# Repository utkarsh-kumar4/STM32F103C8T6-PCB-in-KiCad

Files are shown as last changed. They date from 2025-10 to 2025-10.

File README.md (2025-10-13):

<h1 align="center">⚙️ STM32F103C8T6 Custom PCB in Kicad</h1>

<h2>📘 Overview</h2>
<p>
This project presents a fully designed and routed PCB based on the <b>STM32F103C8T6</b> microcontroller — a popular ARM Cortex-M3 based MCU used widely in embedded systems, control units, and IoT applications. 
The design covers schematic creation, PCB layout, 3D rendering, and Gerber file generation using <b>KiCad 9.0.4</b>. 
The board integrates essential power regulation, programming/debugging headers, and communication interfaces, making it suitable for both learning and prototyping environments.
</p>

<hr>

<h2>🧩 Features</h2>
<ul>
  <li>Microcontroller: <b>STM32F103C8T6</b> (ARM Cortex-M3, 72 MHz, 64 KB Flash)</li>
  <li>Interfaces: UART, I2C, USB, and SWD Debug</li>
  <li>16 MHz Crystal Oscillator for stable system clock</li>
  <li>AMS1117-3.3V linear regulator from USB VBUS (5V to 3.3V)</li>
  <li>On-board BOOT0 switch for flash and system memory booting</li>
  <li>Compact double-layer PCB with decoupling and bulk capacitors</li>
  <li>All standard headers exposed for breadboard-friendly prototyping</li>
</ul>

<hr>

<h2>🔧 Circuit Design Details</h2>

<h3>Microcontroller Section</h3>
<p>
The core of the design revolves around the <b>STM32F103C8T6</b>. Proper pin mapping and peripheral allocation were done using <b>STM32CubeIDE</b> before schematic creation in KiCad. 
The nomenclature follows standard STM32 conventions:
<ul>
  <li><b>VDD / VDDA</b>: 3.3V supply</li>
  <li><b>VSS / VSSA</b>: Ground reference</li>
  <li><b>VBAT</b>: Backup domain supply (optional in this design)</li>
</ul>
</p>

<h3>Power Supply</h3>
<p>
Power is supplied via the USB connector. The <b>AMS1117-3.3V regulator</b> converts 5V (VBUS) to 3.3V for the MCU and peripherals. 
A combination of <b>decoupling capacitors (100nF per VDD pin)</b> and a <b>bulk capacitor (22µF)</b> ensures voltage stability. 
A <b>ferrite bead (FB1)</b> is used for VDDA filtering to isolate analog noise.
</p>

<h3>Clock Circuit</h3>
<p>
A <b>16 MHz crystal oscillator</b> (Y1) provides the external clock source. Load capacitors (C12, C13) are calculated based on crystal datasheet using:
<code>CL = 2 × (C_L - C_stray)</code>. 
The crystal’s ground pads are tied to <b>Crystal_GND24</b> for EMI reduction.
</p>

<h3>Reset and Boot Configuration</h3>
<p>
The <b>NRST</b> pin is connected to a pull-up resistor and reset header, allowing manual or external resets. 
A <b>BOOT0 switch</b> lets users toggle between Flash memory boot and system memory boot modes for easy firmware flashing.
</p>

<h3>USB Interface</h3>
<p>
The <b>Micro USB Type-B connector</b> provides both power and data interface. 
Differential data lines (<b>USB_D+</b> and <b>USB_D−</b>) are routed as a <b>differential pair</b> in KiCad for signal integrity. 
The <b>VBUS</b> pin powers the regulator, and <b>USB shield</b> is tied to board ground through high-value resistance to reduce noise coupling.
</p>

<h3>Communication Interfaces</h3>
<p>
The board exposes the following interfaces:
<ul>
  <li><b>UART</b> – USART1_TX, USART1_RX for serial communication</li>
  <li><b>I2C</b> – I2C1_SCL, I2C1_SDA for sensor and peripheral interfacing</li>
  <li><b>SWD</b> – Serial Wire Debug (PA13, PA14) for programming and debugging</li>
</ul>
These headers simplify firmware upload and real-time debugging using ST-Link or similar tools.
</p>

<hr>

<h2>💻 KiCad Project Workflow</h2>
<p>
The PCB was designed in <b>KiCad</b> following standard embedded design practices. ERC (Electrical Rules Check) and DRC (Design Rules Check) were performed to ensure design integrity before Gerber generation.
</p>

<ul>
  <li><b>ERC:</b> Validates schematic-level connections and symbol consistency.</li>
  <li><b>DRC:</b> Checks trace clearances, copper spacing, and via placements.</li>
  <li><b>Gerber Files:</b> Generated for manufacturing and fabrication verification.</li>
</ul>

<hr>

<h2>🧠 Learnings</h2>
<p>
This project helped reinforce key embedded hardware design concepts:
<ul>
  <li>Understanding STM32 power domains (VDD, VDDA, VBAT)</li>
  <li>Implementing decoupling and bulk capacitors for stable operation</li>
  <li>Applying ferrite beads for analog noise isolation</li>
  <li>Routing differential USB pairs in KiCad</li>
  <li>Debugging using SWD and BOOT0 configuration</li>
  <li>Generating and verifying ERC/DRC-compliant Gerber files</li>
</ul>
It also provided insight into the workflow of transforming a schematic into a professional-grade PCB suitable for embedded applications.
</p>

<hr>

<h2>📷 Project Images</h2>
<h3>🔹 Schematic Design</h3>
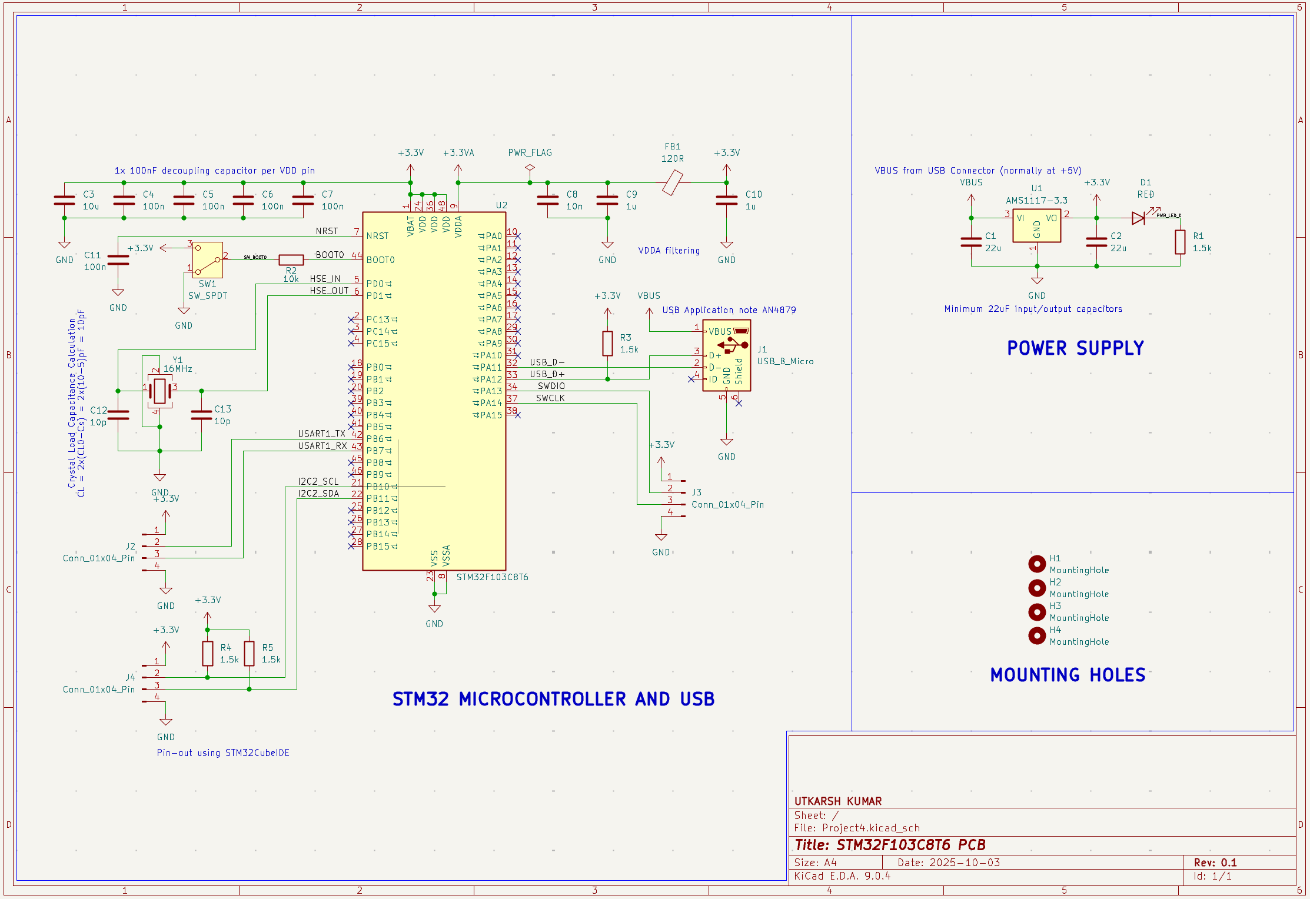
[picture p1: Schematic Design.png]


<h3>🔹 PCB Layout</h3>
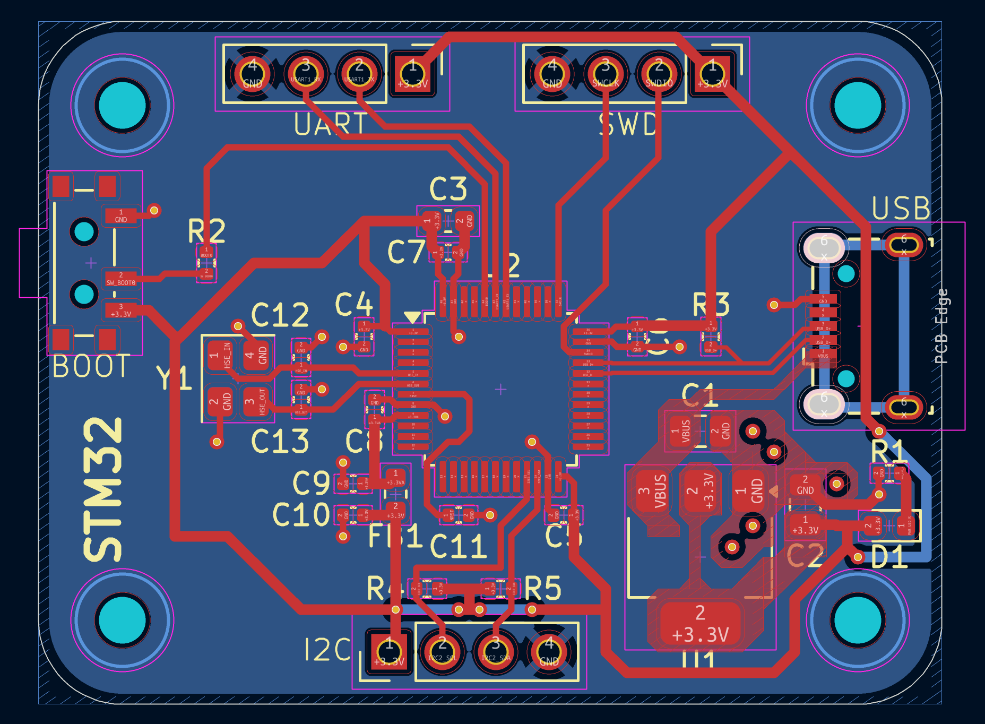
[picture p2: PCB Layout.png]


<h3>🔹 3D Board View</h3>
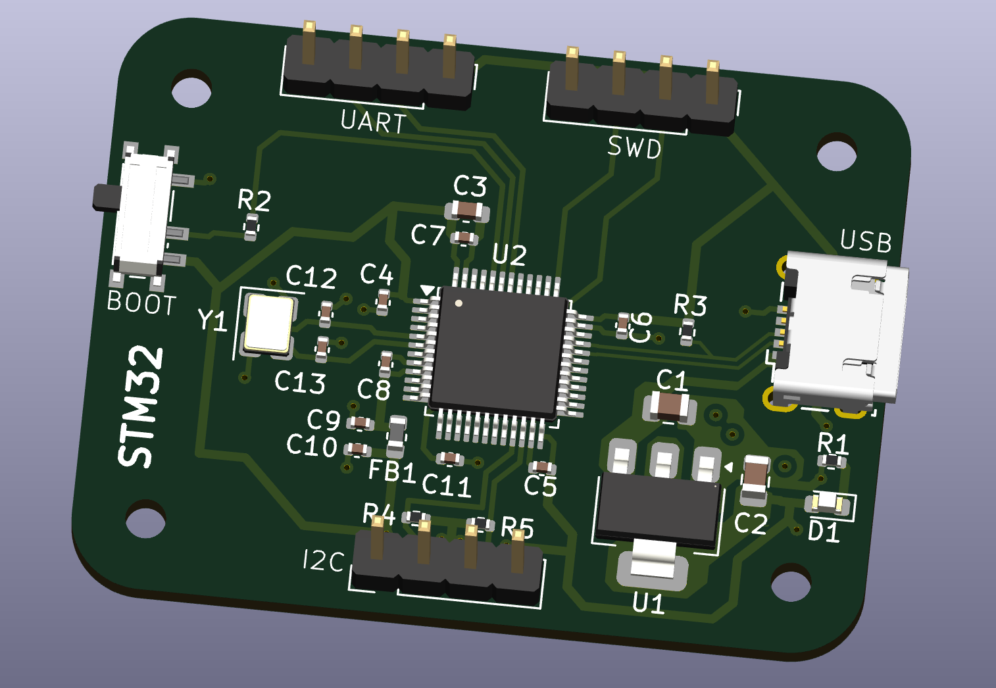
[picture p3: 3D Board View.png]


## Author 👤
[Utkarsh Kumar](https://github.com/utkarsh-kumar4) 👨🏻‍💻🎓

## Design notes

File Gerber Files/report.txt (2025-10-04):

Plotted to '/Users/homefolder/Desktop/KiCad Project/Project4/Project4-F_Cu.gbr'.
Plotted to '/Users/homefolder/Desktop/KiCad Project/Project4/Project4-B_Cu.gbr'.
Plotted to '/Users/homefolder/Desktop/KiCad Project/Project4/Project4-F_Paste.gbr'.
Plotted to '/Users/homefolder/Desktop/KiCad Project/Project4/Project4-B_Paste.gbr'.
Plotted to '/Users/homefolder/Desktop/KiCad Project/Project4/Project4-F_Silkscreen.gbr'.
Plotted to '/Users/homefolder/Desktop/KiCad Project/Project4/Project4-B_Silkscreen.gbr'.
Plotted to '/Users/homefolder/Desktop/KiCad Project/Project4/Project4-F_Mask.gbr'.
Plotted to '/Users/homefolder/Desktop/KiCad Project/Project4/Project4-B_Mask.gbr'.
Plotted to '/Users/homefolder/Desktop/KiCad Project/Project4/Project4-Edge_Cuts.gbr'.
Created Gerber job file '/Users/homefolder/Desktop/KiCad Project/Project4/Project4-job.gbrjob'.
Info: Done.
Plotted to '/Users/homefolder/Desktop/KiCad Project/Project4/Gerber Files/Project4-F_Cu.gbr'.
Plotted to '/Users/homefolder/Desktop/KiCad Project/Project4/Gerber Files/Project4-B_Cu.gbr'.
Plotted to '/Users/homefolder/Desktop/KiCad Project/Project4/Gerber Files/Project4-F_Paste.gbr'.
Plotted to '/Users/homefolder/Desktop/KiCad Project/Project4/Gerber Files/Project4-B_Paste.gbr'.
Plotted to '/Users/homefolder/Desktop/KiCad Project/Project4/Gerber Files/Project4-F_Silkscreen.gbr'.
Plotted to '/Users/homefolder/Desktop/KiCad Project/Project4/Gerber Files/Project4-B_Silkscreen.gbr'.
Plotted to '/Users/homefolder/Desktop/KiCad Project/Project4/Gerber Files/Project4-F_Mask.gbr'.
Plotted to '/Users/homefolder/Desktop/KiCad Project/Project4/Gerber Files/Project4-B_Mask.gbr'.
Plotted to '/Users/homefolder/Desktop/KiCad Project/Project4/Gerber Files/Project4-Edge_Cuts.gbr'.
Created Gerber job file '/Users/homefolder/Desktop/KiCad Project/Project4/Gerber Files/Project4-job.gbrjob'.
Info: Done.
Info: Done.
Info: Done.

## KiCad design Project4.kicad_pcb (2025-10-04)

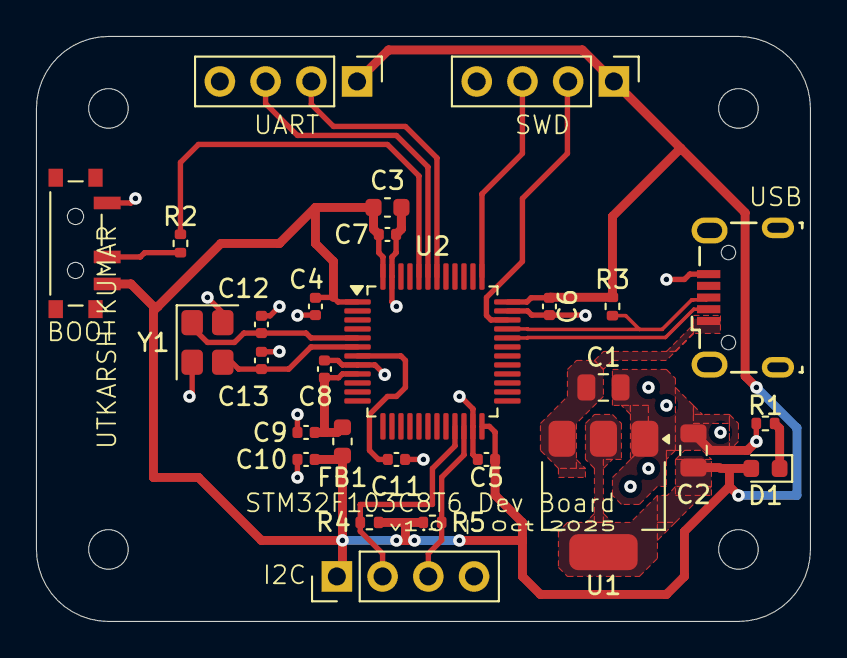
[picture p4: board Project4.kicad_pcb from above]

Board: 2 copper layers, 43.0 x 32.5 mm, 32 parts (0 on the bottom side), 18 nets.

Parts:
C1, C2: 22u; C_0805_2012Metric
C3: 10u; C_0603_1608Metric
C4, C5, C6, C7, C11: 100n; C_0402_1005Metric
C8: 10n; C_0402_1005Metric
C9, C10: 1u; C_0402_1005Metric
C12, C13: 10p; C_0402_1005Metric
D1: RED; LED_0603_1608Metric
FB1: 120R; L_0603_1608Metric
H1, H2, H3, H4: MountingHole; MountingHole_2.2mm_M2
J1: USB_B_Micro; USB_Micro-B_Wuerth_629105150521
J2, J3, J4: Conn_01x04_Pin; PinHeader_1x04_P2.54mm_Vertical
R1, R3, R4, R5: 1.5k; R_0402_1005Metric
R2: 10k; R_0402_1005Metric
SW1: SW_SPDT; SW_SPDT_PCM12
U1: AMS1117-3.3; SOT-223-3_TabPin2
U2: STM32F103C8T6; LQFP-48_7x7mm_P0.5mm
Y1: 16MHz; Crystal_SMD_3225-4Pin_3.2x2.5mm

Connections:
+3.3V: C2.1, C3.1, C4.1, C5.1, C6.1, C7.1, C10.1, D1.2 (A), FB1.2, J2.1, J3.1, J4.1, R3.1, R4.1, R5.1, SW1.3 (C), U1.2 (VO), U2.1 (VBAT), U2.24 (VDD), U2.36 (VDD), U2.48 (VDD)
+3.3VA: C8.1, C9.1, FB1.1, U2.9 (VDDA)
/BOOT0: R2.1, U2.44 (BOOT0)
/HSE_IN: C12.1, U2.5 (PD0), Y1.1
/HSE_OUT: C13.1, U2.6 (PD1), Y1.3
/I2C2_SCL: J4.2, R4.2, U2.21 (PB10)
/I2C2_SDA: J4.3, R5.2, U2.22 (PB11)
/NRST: C11.1, U2.7 (NRST)
/PWR_LED_K: D1.1 (K), R1.1
/SWCLK: J3.3, U2.37 (PA14)
/SWDIO: J3.2, U2.34 (PA13)
/SW_BOOT0: R2.2, SW1.2 (B)
/USART1_RX: J2.3, U2.43 (PB7)
/USART1_TX: J2.2, U2.42 (PB6)
/USB_D+: J1.3 (D+), R3.2, U2.33 (PA12)
/USB_D-: J1.2 (D-), U2.32 (PA11)
GND: C1.2, C2.2, C3.2, C4.2, C5.2, C6.2, C7.2, C8.2, C9.2, C10.2, C11.2, C12.2, C13.2, J1.5 (GND), J2.4, J3.4, J4.4, R1.2, SW1.1 (A), U1.1 (GND), U2.8 (VSSA), U2.23 (VSS), U2.35 (VSS), U2.47 (VSS), Y1.2, Y1.4
VBUS: C1.1, J1.1 (VBUS), U1.3 (VI)
